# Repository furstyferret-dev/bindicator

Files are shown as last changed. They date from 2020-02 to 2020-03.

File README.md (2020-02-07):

# bindicator
## Overview
A bin collection notifier partly inspired by [this Twitter post](https://twitter.com/tarbard/status/1002464120447397888?lang=en) by Darren Tabard. Significant changes include collection schedule download from a Google Calendar, OLED display support, use of two NeoPixel Rings for greater brightness, and a capacitive touch sensor to cancel the reminder.

### Click on images to see videos
Watch the video (https://youtu.be/CMq2k3gbSQc)

## How it works
This is a project in two parts - simple Arduino code running on an ESP8266 handles the WiFi connection, drives the NeoPixel, and regularly downloads calendar events in JSON format from a Google Calendar. On first start it will launch a captive portal access point (SSID "Bindicator"), where you must supply a Google Scripts App ID for your calendar.  

Once connected any collections will cause the Bindicator to light up 24 hours before. Tapping the top of the "bin" will cancel the reminder. Multiple collections (three maximum) on the same day will show as the colour cycling. Colour is determined by the colour chosen for the event in Google Calendar. If the reminder is ignored, it will auto-cancel at 8.00am on the day of collection.

Calendar data is refreshed every 20 minutes.

Watch the video (https://youtu.be/yja5Ed7apo8)

## Make your own
### Parts list
1. [ESP8266 development board with OLED (any ESP8266 will work)](https://www.amazon.co.uk/gp/product/B076S8S6HL/ref=ox_sc_act_title_1?smid=A1QGN06QN25C35&psc=1) OR [Makerfire D1 Mini or clone](https://www.amazon.co.uk/Makerfire-NodeMcu-ESP8266-Internet-Development/dp/B07KYFZD17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)
2. [NeoPixel 7-LED ring (or generic equivalent) * 2](https://www.amazon.co.uk/gp/product/B07L82MSC9/ref=ox_sc_act_title_2?smid=A3TQ6TJY5HYALR&psc=1)
3. [Generic capacitive touch sensor](https://www.amazon.co.uk/ARCELI-2-5-5-5V-Capacitive-Self-Lock-Arduino/dp/B07BVN4CNH/)

### Arduino code
The Arduino code is plug-and-play. Further information on customising the program is available below.

> If you're using a plain ESP8266 board you should comment out the DISPLAY definition on line 18.

### Google script
Instead of trying to download and parse an entire calendar, the heavy lifting is handled by a Google Script. Go to [Google Scripts](https://script.google.com/home) and create a new project. Copy and paste the code from the GoogleScript.gs file, save it, and publish it.

**You need to save the API ID at this point**. This is the section of the URL from /macros/s through to /exec (see below in bold):
> https://script.google.com/macros/s/**AKfycbzcUsdfsdfsdltDtBHlbgde_9fXQvYMuddsvGhHFIGcSl3wr_5k**/exec

You'll need to supply this ID when you set up the Bindicator for the first time, otherwise it'll just show you my bin collection calendar.

### Soldering
Minimal soldering required. You'll need to solder wires to the NeoPixels and touch sensor. The NeoPixels support loop-in-and-out for data, saving a pin on the ESP8266. Dupont jumper wires can be used to connect to the board. I removed the plastic connector and replaced it with thin heat shrink tube to allow more flexibility when squashing everything into the base. 

NeoPixels and the button are happy on either 3.3 or 5V. I would not recommend running both from 3.3V as the on-board regulator will struggle, but the 5V side should be fine, as is a mixture of both.

Important: The D1 Mini only has one ground. Either loop through both NeoPixels and then on to the button, or solder a couple of header pins horizontally to the top of the USB port (common ground). 

### 3D print
I've modified a [fantastic model of a wheelie bin / trash can](https://www.thingiverse.com/thing:1935572) by DrLex. You'll need to download the wheels and axles from Thingiverse because I've not edited them. I've changed the bin model to include a mounting ring for the NeoPixel and a housing for the capacitive touch switch. I'd recommend printing with extra solid layers both on the sides and the top. I've used transparent PLA and white. White is best. Grey definitely doesn't work. :-)

If you use transparent PLA you may wish to print a diffuser which drops on top of the LED ring. This makes the light much easier to see in daylight, and prevents colour fringing effects from the layer lines.

I hot-glued the button and NeoPixel to the lid. 

[Here's the Thingiverse remix](https://www.thingiverse.com/thing:4147342)

Watch the video (https://youtu.be/6T-8IIQMk4Q)

## LED colours
* **Pulsing White**: Connecting to WiFi
* **Solid White**: Downloading calendar data
* **Magenta (at startup)**: WiFi portal running
* **Magenta**: Reminder cancelled
* **Red**: Unable to connect to WiFi

## Troubleshooting
**Can't connect to WiFi.**
The ESP8266 will only connect to 2.4GHz networks. If the captive portal isn't working properly, you can easily hard-code the SSID / password / Google Script ID into the Arduino program.

**I can connect but then see a single red flash**
Check your Google Script ID. This is a response to a 404, which Google returns if the script ID is wrong. See above.

**Corrupted names on the OLED display.**
I think this is a memory leak from the Linked List which handles events. The reality is that I'm not sure why it's happening. If you don't like it just reboot the Bindicator.

**Colours aren't distinctive.**
I'd recommend sticking with strong primary colours (green / blue / orange etc) instead of the paler equivalents. The brightness variable may help here, as would implementing the gamma correction function available from Adafruit. If you don't like them, they're easily corrected (8 bit RGB values).

**Generic "it's not working!"**
The ESP8266 is quite particular over pins used for GPIO, especially at boot. Check the various pin-outs on Google for recommendations. The numbers silk-screened onto the board do not correspond with the Arduino IDE assignment. 

You could also uncomment the DEBUG flag in the DebugMacros.h file which will provide more information through the serial monitor.

## Improvements
Reducing the reliance on hot-glue would be a start. I wasn't aware of NeoPixel linear boards when I built this, which could be used to create some very interesting effects if mounted on the inside back wall of the model.

## Thanks
* Darren Tabard [for the inspiration](https://twitter.com/tarbard/status/1002464120447397888?lang=en).
* DrLex for the [incredible 3D model](https://www.thingiverse.com/thing:1935572).
* Adafruit for their NeoPixel Library.
* Arkhipenko for the [TaskScheduler Library](https://github.com/arkhipenko/TaskScheduler) library.
* ElectronicsGuy for his [HTTPSRedirect library](https://github.com/electronicsguy/ESP8266/tree/master/HTTPSRedirect), without which this wouldn't be possible.
* Olikraus's [u8g2 display library and fonts](https://github.com/olikraus/u8g2).
* [ArduinoJSON](https://arduinojson.org/).

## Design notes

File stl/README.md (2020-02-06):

### 3D model remixed from original Thingiverse design:
https://www.thingiverse.com/thing:1935572

### Thingiverse link:
https://www.thingiverse.com/thing:4147342

### Changes made:
* Base added
* Cutout in bottom for wiring / header pins
* Neopixel holders
* Lid modified to hold capacitive touch sensor
* Cable routing

### Print settings:
Printed on a Flashforge Finder using white PLA, temperature 190C. 0.12mm layer thickness with four perimeter walls and supports under the wheel arches.

Infil is 3D at 10% on the body, and default hexagon on the base.

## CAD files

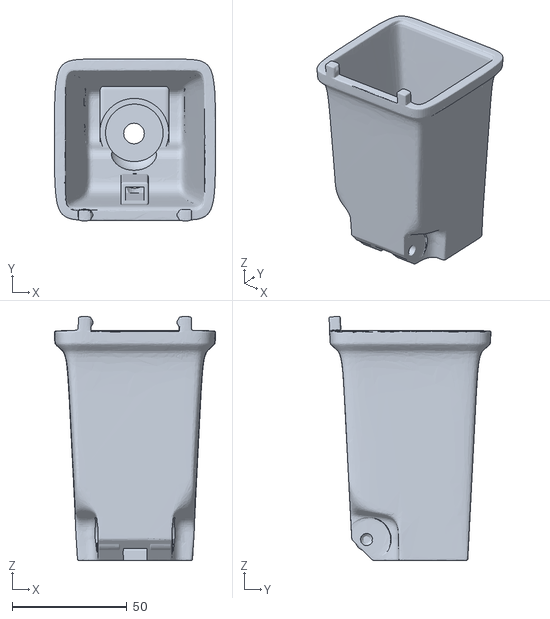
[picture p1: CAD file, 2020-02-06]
stl/Bin Body.stl
70.1 x 70.4 x 106.1

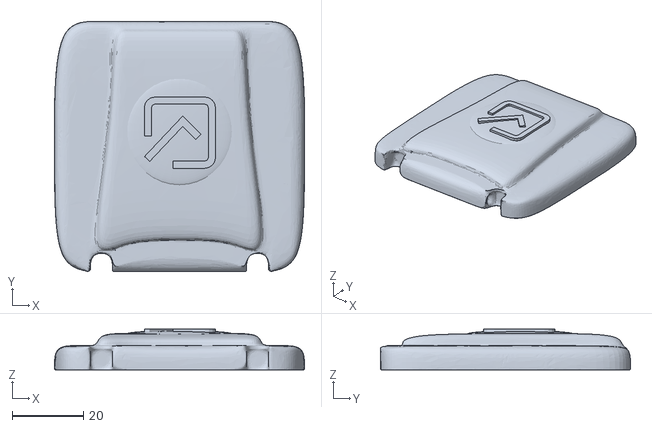
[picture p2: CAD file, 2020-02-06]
stl/Lid (no supports).stl
70.2 x 70.2 x 11.5

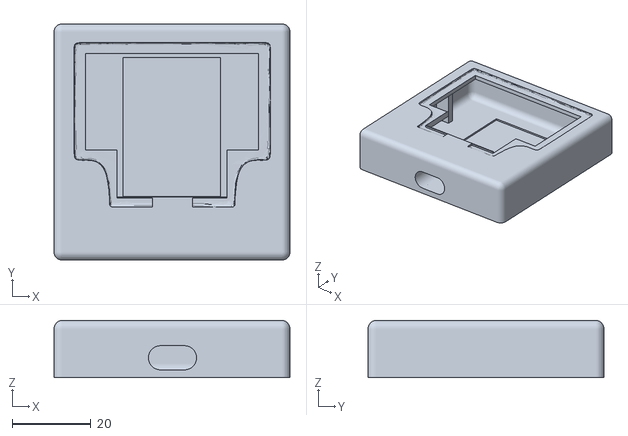
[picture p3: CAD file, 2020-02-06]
stl/Base.stl
60.0 x 60.0 x 14.5

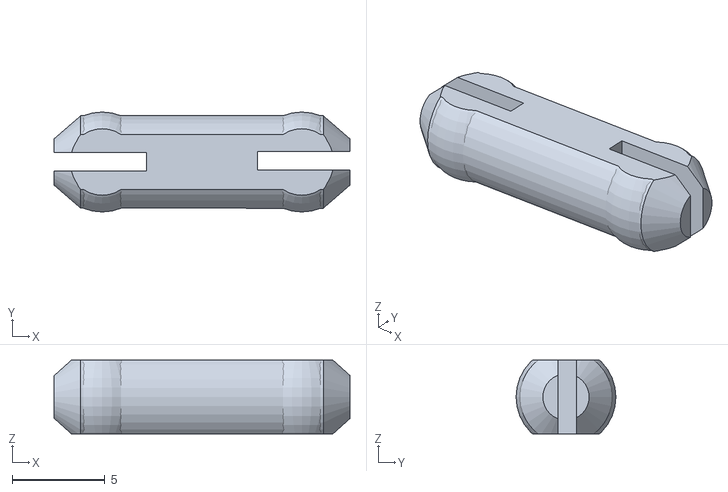
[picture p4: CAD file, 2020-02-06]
stl/TrashCan-axle.stl
16.0 x 5.40 x 4.00

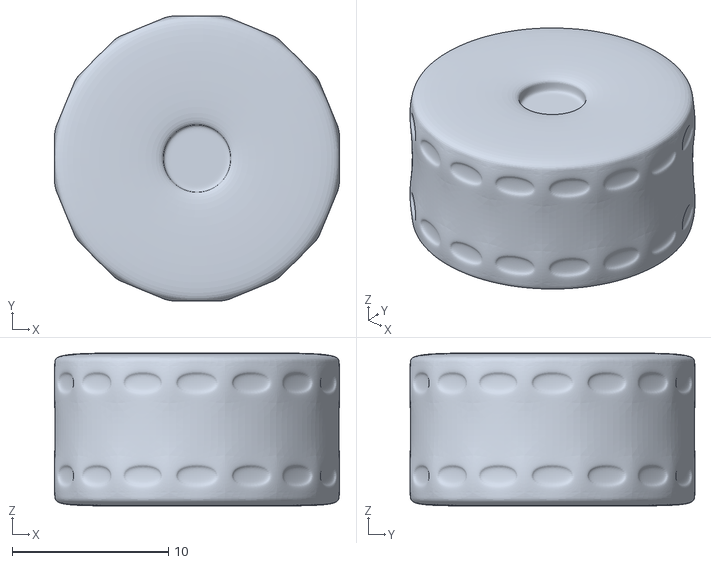
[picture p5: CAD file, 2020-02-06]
stl/TrashCan-wheel.stl
18.2 x 18.2 x 9.78

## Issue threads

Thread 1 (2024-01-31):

STL file missing

Craig-Ingram, 2024-01-31:
Hello, I get a 404 error when I click the link for the modified STL. Can you please reupload?
Cheers

Craig-Ingram, 2024-01-31:
Found the SLT on the repo. Thanks

Closed 2024-01-31.

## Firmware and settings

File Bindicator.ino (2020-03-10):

#include <FS.h>
#include <WiFiManager.h>
#include <TaskScheduler.h>
#include <TaskSchedulerDeclarations.h>
#include <TaskSchedulerSleepMethods.h>
#include <U8g2lib.h>
#include <ArduinoJson.h>
#include <ESP8266WiFi.h>
#include <Adafruit_NeoPixel.h>
#include <WS2812FX.h>
#include "HTTPSRedirect.h"
#include "LinkedList.h"
#include "DebugMacros.h"

#define SECOND            1000
#define MINUTE            SECOND * 60
#define HOUR              MINUTE * 60

//#define DISPLAY                             // Comment out if your ESP8266 doesn't have a display
#define POWER_LED         true                // Illuminate the built-in LED when power supplied       
#define VERSION           "v3.10b"            // Version information
#define PORTAL_SSID       "Bindicator"        // SSID for web portal
#define SCROLLING         true                // If false, use the button to change page
#define LED_PIN           15                  // NeoPixel data pin
#define TOUCH_PIN         13                  // Capacitive touch data pin
#define RESET_PIN         16                  // Display reset
#define CLOCK_PIN         5                   // Display clock
#define DATA_PIN          4                   // Display data
#define LED_COUNT         12                  // Number of pixels
#define BRIGHTNESS        255                 // NeoPixel brightness (0 - 255)
#define SPEED             1000                // Animation speed (lower is faster)
#define WIFI_TIMEOUT      5 * SECOND          // Delay in seconds before WiFi connection times out
#define WATCHDOG_TIMEOUT  60 * SECOND         // Delay in seconds before watchdog reboots device
#define CONFIG_DELAY      3 * SECOND          // Delay in seconds before enabling WiFi config at boot
#define LED_INTERVAL      2 * SECOND          // Interval in second between event colour changing
#define REFRESH_INTERVAL  10 * MINUTE         // Data refresh interval
#define NIGHT_BRT         150                  // Night light brightness (0 - 255)
#define HALOGEN_HUE       5643                // Night light colour temperature
#define HALOGEN_SAT       80                  // Night light saturation

int modes[3] = { FX_MODE_STATIC, FX_MODE_RAINBOW, FX_MODE_CUSTOM };
int modeIndex = FX_MODE_STATIC; 

struct Event {                          // All events contain a title and associated colour
  const char* title;                    
  uint32_t color;
};

LinkedList<struct Event> eventList;     // Downloaded calendar events go here

Adafruit_NeoPixel pixel = Adafruit_NeoPixel(LED_COUNT, LED_PIN, NEO_GRB + NEO_KHZ800);
WS2812FX ws2812fx = WS2812FX(LED_COUNT, LED_PIN, NEO_GRB + NEO_KHZ800);

#ifdef DISPLAY
U8G2_SSD1306_128X32_UNIVISION_F_HW_I2C u8g2(U8G2_R0, RESET_PIN, CLOCK_PIN, DATA_PIN);
int page;                               // Incremented to change page when button touched and no collection scheduled
#endif

const char* host = "script.google.com";                                           // Base URL for Google Apps
const int httpsPort = 443;                                                        // Default HTTPS port
char *GScriptId = "xxxxxxxxxxxxxxxxxxxxxxxxxxxxxxxxxxxxxxxxxxxxxxxxxxxxxxxx";     // Default script ID

String eventsUrl = String("/macros/s/") + GScriptId + "/exec";                    // URL to retrieve calendar entries [GET]
String clearUrl = String("/macros/s/") + GScriptId + "/exec?clear";               // URL to clear active events [POST]

HTTPSRedirect* client = nullptr;                                                  // This client handles the redirection used by Google
WiFiManagerParameter custom_gScriptId(                                            // Custom parameter if Google Script ID is changed
  "gscriptid", "Google App ID", GScriptId, 56);

void neopixelCallback();                                                          // Task scheduler function for updating the NeoPixel and display
void getEventsCallback();                                                         // Task scheduler function for refreshing event data
void cancelEventsCallback();                                                      // Task scheduler function for cancelling upcoming events
void wiFiWatchdogCallback();                                                      // Task scheduler function for monitoring WiFi connection

Scheduler ts;                                                                     // Responsible for all repeating functions
Task tShowEventColor(LED_INTERVAL, TASK_FOREVER, &neopixelCallback);              // Task to convert events to NeoPixel colours
Task tUpdateData(REFRESH_INTERVAL, TASK_FOREVER, &getEventsCallback);             // Task to update the list of calendar events
Task tCancelEvents(SECOND / 2, TASK_FOREVER, &cancelEventsCallback);              // Task to poll the capacitive button
Task tWiFiWatchdog(SECOND, TASK_FOREVER, &wiFiWatchdogCallback);                  // Task to monitor WiFi and reconnect if necessary
  

void setup() {
  pinMode(TOUCH_PIN, INPUT);                 // Set the pin connected to the touch sensor to input
  if (POWER_LED) {                           // Turn on the built-in LED if enabled above
  pinMode(LED_BUILTIN, OUTPUT);
  digitalWrite(LED_BUILTIN, LOW);
  }

  delay(1000);

#ifdef DEBUG
  Serial.begin(115200);                     
  Serial.flush();
  DPRINTLN("Serial Transmission Begin");
#endif

  initialiseNeoPixel();                     // NeoPixel won't work without initialisation

#ifdef DISPLAY
  u8g2.begin();
  u8g2.setFontMode(0);                      // Enable transparent mode, which is faster
  u8g2.clearBuffer();                       // Clear the internal memory
  u8g2.setFont(u8g2_font_helvR14_tr);       // Choose a suitable font
  u8g2.drawStr(20, 14, "Bindicator");
  u8g2.setFont(u8g2_font_helvR14_tr);
  u8g2.drawStr(38, 32, VERSION);
  u8g2.sendBuffer();                        // Transfer internal memory to the display
#endif

  DPRINTLN("Mounting FS...");
  if (SPIFFS.begin()) {                                                 // If file system is valid get configuration data
    DPRINTLN("Mounted file system");
    if (SPIFFS.exists("/config.json")) {                                // File exists, reading and loading

      DPRINTLN("Reading config file");
      File configFile = SPIFFS.open("/config.json", "r");
      if (configFile) {
        DPRINTLN("Opened config file");
        size_t size = configFile.size();
        std::unique_ptr<char[]> buf(new char[size]);                   // Allocate a buffer to store contents of the file
        configFile.readBytes(buf.get(), size);

        DynamicJsonDocument doc(size);                                 // Deserialise JSON data
        deserializeJson(doc, buf.get());
        DeserializationError err = deserializeJson(doc, buf.get());

        if (!err) {
          JsonObject root = doc[0];                                    // If the config file is valid, copy the script ID
          strcpy(GScriptId, root["GScriptId"]);
        }
        configFile.close();
      }
    }
  } else {
    DPRINTLN("Failed to mount FS");
  }

  unsigned long startTime = millis();
  ws2812fx.setMode(FX_MODE_COLOR_WIPE);
  ws2812fx.setColor(MAGENTA);
  while (digitalRead(TOUCH_PIN) == HIGH)      // If so wait until approx 5 seconds have passed
  {                                           // then start WiFi Configuration
    DPRINTLN("Touch pin high");
    if (millis() > startTime + (CONFIG_DELAY))
    {
      configWiFi();   
      return;
    }    
    ws2812fx.service();
  }

  DPRINTLN();                               // Debugging info
  DPRINT("Connecting to WiFi: ");

  WiFi.softAPdisconnect(true);              // Stop broadcasting SSID from setup mode (ESP8266 bug)
  WiFi.begin();  
  
  ws2812fx.setColor(WHITE);
  ws2812fx.setMode(FX_MODE_FADE);           
  
  startTime = millis();  
  while (WiFi.status() != WL_CONNECTED) {
    ws2812fx.service();
    DPRINT(".");
    if (millis() > startTime + (WIFI_TIMEOUT)) 
    {                                                   // It's trivial to change this to start WiFi configuration
      ws2812fx.fill(ws2812fx.ColorHSV(RED));            // at this point.
      ws2812fx.show();
      DPRINTLN();
      DPRINTLN("WiFi Timeout");
      while (true) 
      { 
        if (millis() < WATCHDOG_TIMEOUT)        // Wait 60 seconds then reboot in attempt to recover WiFi
          ESP.wdtFeed(); 
        }
#ifdef DISPLAY
      u8g2.clearBuffer();                       // Clear the internal memory
      u8g2.setFont(u8g2_font_helvR14_tr);       // Choose a suitable font
      u8g2.drawStr(0, 14, "Error joining");     // Write title to the buffer
      u8g2.drawStr(0, 32, "WiFi network");
      u8g2.sendBuffer();                        // Transfer internal memory to the display
#endif
      return;
    }
  }
  DPRINTLN("");                             // Debugging info
  DPRINTLN("WiFi connected");
  DPRINTLN("IP address: ");
  DPRINTLN(WiFi.localIP());

  ts.init();                                // Task Scheduler initialisation
  ts.addTask(tShowEventColor);              // Add tasks
  ts.addTask(tUpdateData);                  // ...
  ts.addTask(tCancelEvents);                // ...
  ts.addTask(tWiFiWatchdog);                // ....
  tUpdateData.enable();                     // Connected and ready to start getting event data
  tCancelEvents.enable();                   // Allow use of capacitive button
  tWiFiWatchdog.enable();
}

void loop() {
  ts.execute();                               // Task scheduler handles all repeating functions
  ws2812fx.service();                         // WS2812 animation 
}

void neopixelCallback() {
  DPRINTLN(ESP.getFreeHeap());  
  if (eventList.getLength() > 0)              // If items to show...
  {
    switch (eventList.getLength())
    {
      case 1:
      if (ws2812fx.getMode() != FX_MODE_BREATH)
        ws2812fx.setMode(FX_MODE_BREATH);
      break;

      case 2:
      if (ws2812fx.getMode() != FX_MODE_STATIC)
        ws2812fx.setMode(FX_MODE_STATIC);
      break;

      default:
      if (ws2812fx.getMode() != FX_MODE_STATIC)
        ws2812fx.setMode(FX_MODE_STATIC);
    }
    
    struct Event e = eventList.getCurrent();
    ws2812fx.setColor(e.color);
    eventList.loop();                         // Move to the next item
#ifdef DISPLAY
    u8g2.clearBuffer();                       // Clear the internal memory
    u8g2.setFont(u8g2_font_helvR14_tr);       // Choose a suitable font
    u8g2.drawStr(0, 14, "Next collection");   // Write title to the buffer
    u8g2.drawStr(0, 32, e.title);
    DPRINTLN(e.title);
    u8g2.sendBuffer();                        // Transfer internal memory to the display
#endif
  } else
  {
    tidyUp();

#ifdef DISPLAY
    switch (page % 3)
    {
      case 0:                                     // Page 1
        u8g2.clearBuffer();                       // Clear the internal memory
        u8g2.setFont(u8g2_font_helvR14_tr);       // Choose a suitable font
        u8g2.drawStr(0, 14, "Free heap");         // Write the free heap to the buffer
        char buf[32];
        itoa(ESP.getFreeHeap(), buf, 10);
        u8g2.drawStr(0, 32, buf);
        u8g2.drawStr(53, 32, "kb");
        u8g2.sendBuffer();                        // Transfer internal memory to the display
        break;

      case 1:                                     // Page 2
        u8g2.clearBuffer();                       // Clear the internal memory
        u8g2.setFont(u8g2_font_helvR14_tr);       // Choose a suitable font
        u8g2.drawStr(0, 14, "IP address");        // Write the title to the buffer
        u8g2.drawStr(0, 32, 
        WiFi.localIP().toString().c_str());       // Write the IP address to the buffer
        u8g2.sendBuffer();                        // Transfer internal memory to the display
        break;

      case 2:                                     // Page 3
        long t = 
        ts.timeUntilNextIteration(tUpdateData);   // Time until task runs again in millis
        u8g2.clearBuffer();                       // Clear the internal memory
        u8g2.setFont(u8g2_font_helvR14_tr);       // Choose a suitable font
        if (t == 0) {
          u8g2.drawStr(0, 14, "Next check");
          u8g2.drawStr(0, 32, "in progress.");
        }
        if (t == -1) {
          u8g2.drawStr(0, 14, "Calendar sync");
          u8g2.drawStr(0, 32, "is disabled.");
        }
        else {
          const char* text = showTimeFormatted(t);
          int mins = t / 60000;
          DPRINTLN(text);
          u8g2.drawStr(0, 14, "Next update");
          u8g2.drawStr(22, 32, "mins");
          u8g2.setCursor(0, 32);       
          u8g2.print(mins);
        }
        u8g2.sendBuffer();
    }
  }
#endif
}

void cancelEventsCallback() {
  if (digitalRead(TOUCH_PIN) == HIGH && eventList.getLength() > 0)   // Only run if the button is held down
  {                                                                  // and there are events to cancel
#ifdef DISPLAY
    u8g2.clearBuffer();                       // Clear the internal memory
    u8g2.setFont(u8g2_font_helvR14_tr);       // Choose a suitable font
    u8g2.drawStr(0, 14, "Cancelling");        // Write title to the buffer
    u8g2.drawStr(0, 32, "reminder...");
    u8g2.sendBuffer();                        // Transfer internal memory to the display
#endif
    ws2812fx.setColor(MAGENTA);
    ws2812fx.setMode(FX_MODE_STATIC);
    ws2812fx.service();

    // Use HTTPSRedirect class to create a new TLS connection
    client = new HTTPSRedirect(httpsPort);
    client->setInsecure();
    client->setPrintResponseBody(true);
    client->setContentTypeHeader("application/json");

    DPRINT("Connecting to ");
    DPRINTLN(host);

    // Try to connect for a maximum of 5 times
    bool flag = false;
    for (int i = 0; i < 5; i++) {
      int retval = client->connect(host, httpsPort);
      if (retval == 1) {
        flag = true;
        break;
      }
      else
        DPRINTLN("Connection failed. Retrying...");
    }

    if (!flag) {
      DPRINT("Could not connect to server: ");
      DPRINTLN(host);
      DPRINTLN("Exiting...");
      return;
    }

    client->POST(clearUrl, host, "", false);        // Send empty POST string

    delete client;                                  // Delete HTTPSRedirect object
    client = nullptr;                               // COMMENT THIS LINE IF PROGRAM CRASHES

    tidyUp();

    eventList.Clear();                              // Empty the event list
    getEventsCallback();                            // Update events list to make sure they were
    return;                                         // successfully cancelled
  }

#ifdef DISPLAY
  if (!SCROLLING && digitalRead(TOUCH_PIN) == HIGH)
      page++;                                       // Increment page number (modulo)
      else
        page++;
#endif

  unsigned long startTime = millis();
  if (digitalRead(TOUCH_PIN) == HIGH && eventList.getLength() == 0) 
  {
      modeIndex++;                                  // Cycle nightlight modes
      modeIndex = modeIndex % 3;
      ws2812fx.setMode(modes[modeIndex]);
      tidyUp();
      DPRINT("Mode: ");
      DPRINTLN(modeIndex);
  }
  }

void getEventsCallback()
{
  DPRINTLN(ESP.getFreeHeap());

  client = new HTTPSRedirect(httpsPort);            
  client->setInsecure();
  client->setPrintResponseBody(true);
  client->setContentTypeHeader("application/json"); // Expecting a JSON response

  DPRINTLN("Connecting to ");
  DPRINTLN(host);

  // Try to connect for a maximum of 5 times
  bool flag = false;
  for (int i = 0; i < 5; i++) {
    int retval = client->connect(host, httpsPort);
    if (retval == 1) {
      flag = true;
      break;
    }
    else
      DPRINTLN("Connection failed. Retrying...");
  }

  if (!flag) {
    DPRINTLN("Could not connect to server: ");
    DPRINTLN(host);
    DPRINTLN("Exiting...");
    return;
  }

  if (client->GET(eventsUrl, host))
    if (client->getStatusCode() == 200)             // Valid response
    {
      DPRINTLN(ESP.getFreeHeap());
      DPRINTLN("Response Body: ");
      parseJson(client->getResponseBody());
      DPRINT(client->getResponseBody());
    }

    if (client->getStatusCode() == 404)             // 404 - script ID probably wrong
    {
      DPRINTLN("404 - confirm Gscript ID");
      pixel.fill(pixel.ColorHSV(RED));         
      pixel.show();
#ifdef DISPLAY
      u8g2.clearBuffer();                         // Clear the internal memory
      u8g2.setFont(u8g2_font_helvR14_tr);         // Choose a suitable font
      u8g2.drawStr(0, 14, "Update failed");       // Write title to the buffer
      u8g2.drawStr(0, 32, "Check API ID");
      u8g2.sendBuffer();                          // Transfer internal memory to the display
#endif
    }

  // Delete HTTPSRedirect object
  delete client;
  client = nullptr;
  tShowEventColor.enableDelayed(SECOND * 3);      // Brief delay so errors visible to user
}

void parseJson(String json) {

  const size_t capacity = JSON_ARRAY_SIZE(3) + 3 * JSON_OBJECT_SIZE(2) + 1024; // Additional bytes for string duplication
  DynamicJsonDocument doc(capacity);

  deserializeJson(doc, json);
  DeserializationError err = deserializeJson(doc, json);

  if (err) {
    DPRINTLN(F("deserializeJson() failed with code "));
    DPRINTLN(err.c_str());
    return;
  }

  JsonObject root;                                 // This object contains an array of JSON events
  eventList.Clear();                               
  for (int i = 0; i < doc.size(); i++)
  {
    DPRINTLN(ESP.getFreeHeap());
    struct Event e;                                // For each event, create a struct and populate data
    root = doc[i];
    e.title = root["title"];
    e.color = eventColor2RealColor(atoi(root["color"]));
    eventList.Append(e);                           // Add event to list
  }
}

/******************** WIFI FUNCTIONS ************************/

void configWiFi() {
#ifdef DISPLAY
    u8g2.clearBuffer();                       // Clear the internal memory
    u8g2.setFont(u8g2_font_helvR14_tr);       // Choose a suitable font
    u8g2.drawStr(24, 23, "WiFi Setup");       // Write title to the buffer
    u8g2.sendBuffer();                        // Transfer internal memory to the display
#endif

  WiFiManager wifiManager;                                 // Handles WiFi configuration via captive portal
  wifiManager.setSaveConfigCallback(saveConfigCallback);   // This function called if data updated
  wifiManager.addParameter(&custom_gScriptId);             // Add a custom parameter for the Google Apps ID
  wifiManager.startConfigPortal(PORTAL_SSID);              // Start an open access point
  DPRINTLN("Wifi Configuration started");
}

void saveConfigCallback()
{
  strcpy(GScriptId, custom_gScriptId.getValue());          // Read updated parameters

  DPRINTLN("Saving config");
  StaticJsonDocument<128> doc;                             
  doc["GScriptId"] = GScriptId;                            

  File configFile = SPIFFS.open("/config.json", "w");      
  if (!configFile) {
    DPRINTLN("Failed to open config file for writing");
  }

  if (serializeJson(doc, configFile) == 0) {
    DPRINTLN(F("Failed to write to file"));
  }
  configFile.close();

  DPRINTLN("Restarting in 5 seconds");
#ifdef DISPLAY
    u8g2.clearBuffer();                       // Clear the internal memory
    u8g2.setFont(u8g2_font_helvR14_tr);       // Choose a suitable font
    u8g2.drawStr(0, 14, "Restarting");        // Write title to the buffer
    u8g2.drawStr(0, 32, "in 5 seconds");
    u8g2.sendBuffer();                        // Transfer internal memory to the display
#endif
  delay(5000);
  ESP.restart();
}

void wiFiWatchdogCallback() {
  unsigned long startTime = millis();
  
  while (WiFi.status() != WL_CONNECTED)
  {
    if (millis() > startTime + WATCHDOG_TIMEOUT)
      ESP.restart();
    ws2812fx.setColor(RED);
    ws2812fx.setBrightness(BRIGHTNESS);
    ws2812fx.setMode(FX_MODE_BLINK);
    ws2812fx.service();
    WiFi.begin();
  }
}

/********************** NEOPIXEL HELPER FUNCTIONS ***************************/

// Needed to use the WS2812 LEDs
// MUST BE CALLED
void initialiseNeoPixel()
{
  ws2812fx.init();
  ws2812fx.setBrightness(BRIGHTNESS);
  ws2812fx.setSpeed(SPEED);
  ws2812fx.setColor(0x007BFF);
  ws2812fx.setMode(FX_MODE_STATIC);
  ws2812fx.setCustomMode(customEffect);
  ws2812fx.start();
}

uint32_t eventColor2RealColor(int eventColor)
{
  switch (eventColor)
  {
    case 0:
      return PINK;
      break;

    case 1:
      return CYAN;
      break;

    case 2:
      return ws2812fx.Color(75, 255, 120);
      break;

    case 3:
      return ws2812fx.Color(190, 175, 255);
      break;

    case 4:
      return ws2812fx.Color(255, 50, 50);
      break;

    case 5:
      return YELLOW;
      break;

    case 6:
      return ORANGE;
      break;

    case 7:
      return CYAN;
      break;

    case 8:
      return WHITE;
      break;

    case 9:
      return BLUE;
      break;

    case 10:
      return GREEN;
      break;

    case 11:
      return RED;
      break;

    default:
      return WHITE;
  }
}

void tidyUp() {
  if (ws2812fx.getMode() != modes[modeIndex])
      ws2812fx.setMode(modes[modeIndex]);
//    if (ws2812fx.getMode() == FX_MODE_STATIC)
//      ws2812fx.setColor(ws2812fx.ColorHSV(0, 0, NIGHT_BRT));
    if (ws2812fx.getMode() == FX_MODE_STATIC)
      ws2812fx.setColor(ws2812fx.gamma32(ws2812fx.ColorHSV(HALOGEN_HUE, HALOGEN_SAT, NIGHT_BRT)));
    if (ws2812fx.getMode() == FX_MODE_FIRE_FLICKER_SOFT)
      ws2812fx.setColor(0xE25822);
    if (ws2812fx.getMode() == FX_MODE_COMET || ws2812fx.getMode() == FX_MODE_LARSON_SCANNER)
      ws2812fx.setColor(0x0000FF);    
}

uint16_t customEffect(void) { 
  WS2812FX::Segment* seg = ws2812fx.getSegment(); 
  ws2812fx.clear();
  return seg->speed; // Return the delay until the next animation step (in ms)
}
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

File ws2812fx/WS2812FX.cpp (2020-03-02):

/*
  WS2812FX.cpp - Library for WS2812 LED effects.

  Harm Aldick - 2016
  www.aldick.org


  FEATURES
    * A lot of blinken modes and counting
    * WS2812FX can be used as drop-in replacement for Adafruit NeoPixel Library

  NOTES
    * Uses the Adafruit NeoPixel library. Get it here:
      https://github.com/adafruit/Adafruit_NeoPixel



  LICENSE

  The MIT License (MIT)

  Copyright (c) 2016  Harm Aldick

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

  CHANGELOG

  2016-05-28   Initial beta release
  2016-06-03   Code cleanup, minor improvements, new modes
  2016-06-04   2 new fx, fixed setColor (now also resets _mode_color)
  2017-02-02   added external trigger functionality (e.g. for sound-to-light)
  2017-02-02   removed "blackout" on mode, speed or color-change
  2017-09-26   implemented segment and reverse features
  2017-11-16   changed speed calc, reduced memory footprint
  2018-02-24   added hooks for user created custom effects
*/

#include "WS2812FX.h"

void WS2812FX::init() {
  resetSegmentRuntimes();
  Adafruit_NeoPixel::begin();
}

// void WS2812FX::timer() {
//     for (int j=0; j < 1000; j++) {
//       uint16_t delay = (this->*_mode[SEGMENT.mode])();
//     }
// }

void WS2812FX::service() {
  if(_running || _triggered) {
    unsigned long now = millis(); // Be aware, millis() rolls over every 49 days
    bool doShow = false;
    for(uint8_t i=0; i < _num_segments; i++) {
      _segment_index = i;
      CLR_FRAME;
      if(now > SEGMENT_RUNTIME.next_time || _triggered) {
        SET_FRAME;
        doShow = true;
        uint16_t delay = (this->*_mode[SEGMENT.mode])();
        SEGMENT_RUNTIME.next_time = now + max(delay, SPEED_MIN);
        SEGMENT_RUNTIME.counter_mode_call++;
      }
    }
    if(doShow) {
      delay(1); // for ESP32 (see https://forums.adafruit.com/viewtopic.php?f=47&t=117327)
      show();
    }
    _triggered = false;
  }
}

// overload setPixelColor() functions so we can use gamma correction
// (see https://learn.adafruit.com/led-tricks-gamma-correction/the-issue)
void WS2812FX::setPixelColor(uint16_t n, uint32_t c) {
  if(IS_GAMMA) {
    uint8_t w = (c >> 24) & 0xFF;
    uint8_t r = (c >> 16) & 0xFF;
    uint8_t g = (c >>  8) & 0xFF;
    uint8_t b =  c        & 0xFF;
    Adafruit_NeoPixel::setPixelColor(n, gamma8(r), gamma8(g), gamma8(b), gamma8(w));
  } else {
    Adafruit_NeoPixel::setPixelColor(n, c);
  }
}

void WS2812FX::setPixelColor(uint16_t n, uint8_t r, uint8_t g, uint8_t b) {
  if(IS_GAMMA) {
    Adafruit_NeoPixel::setPixelColor(n, gamma8(r), gamma8(g), gamma8(b));
  } else {
    Adafruit_NeoPixel::setPixelColor(n, r, g, b);
  }
}

void WS2812FX::setPixelColor(uint16_t n, uint8_t r, uint8_t g, uint8_t b, uint8_t w) {
  if(IS_GAMMA) {
    Adafruit_NeoPixel::setPixelColor(n, gamma8(r), gamma8(g), gamma8(b), gamma8(w));
  } else {
    Adafruit_NeoPixel::setPixelColor(n, r, g, b, w);
  }
}

void WS2812FX::copyPixels(uint16_t dest, uint16_t src, uint16_t count) {
  uint8_t *pixels = getPixels();
  uint8_t bytesPerPixel = getNumBytesPerPixel(); // 3=RGB, 4=RGBW

  memmove(pixels + (dest * bytesPerPixel), pixels + (src * bytesPerPixel), count * bytesPerPixel);
}

// overload show() functions so we can use custom show()
void WS2812FX::show(void) {
  if(customShow == NULL) {
    Adafruit_NeoPixel::show();
  } else {
    customShow();
  }
}

void WS2812FX::start() {
  resetSegmentRuntimes();
  _running = true;
}

void WS2812FX::stop() {
  _running = false;
  strip_off();
}

void WS2812FX::pause() {
  _running = false;
}

void WS2812FX::resume() {
  _running = true;
}

void WS2812FX::trigger() {
  _triggered = true;
}

void WS2812FX::setMode(uint8_t m) {
  setMode(0, m);
}

void WS2812FX::setMode(uint8_t seg, uint8_t m) {
  resetSegmentRuntime(seg);
  _segments[seg].mode = constrain(m, 0, MODE_COUNT - 1);
}

void WS2812FX::setOptions(uint8_t seg, uint8_t o) {
  _segments[seg].options = o;
}

void WS2812FX::setSpeed(uint16_t s) {
  setSpeed(0, s);
}

void WS2812FX::setSpeed(uint8_t seg, uint16_t s) {
//  resetSegmentRuntime(seg);
  _segments[seg].speed = constrain(s, SPEED_MIN, SPEED_MAX);
}

void WS2812FX::increaseSpeed(uint8_t s) {
  uint16_t newSpeed = constrain(SEGMENT.speed + s, SPEED_MIN, SPEED_MAX);
  setSpeed(newSpeed);
}

void WS2812FX::decreaseSpeed(uint8_t s) {
  uint16_t newSpeed = constrain(SEGMENT.speed - s, SPEED_MIN, SPEED_MAX);
  setSpeed(newSpeed);
}

void WS2812FX::setColor(uint8_t r, uint8_t g, uint8_t b) {
  setColor(((uint32_t)r << 16) | ((uint32_t)g << 8) | b);
}

void WS2812FX::setColor(uint8_t r, uint8_t g, uint8_t b, uint8_t w) {
  setColor((((uint32_t)w << 24)| ((uint32_t)r << 16) | ((uint32_t)g << 8)| ((uint32_t)b)));
}

void WS2812FX::setColor(uint32_t c) {
  setColor(0, c);
}

void WS2812FX::setColor(uint8_t seg, uint32_t c) {
//  resetSegmentRuntime(seg);
  _segments[seg].colors[0] = c;
}

void WS2812FX::setColors(uint8_t seg, uint32_t* c) {
//  resetSegmentRuntime(seg);
  for(uint8_t i=0; i<NUM_COLORS; i++) {
    _segments[seg].colors[i] = c[i];
  }
}

void WS2812FX::setBrightness(uint8_t b) {
  b = constrain(b, BRIGHTNESS_MIN, BRIGHTNESS_MAX);
  Adafruit_NeoPixel::setBrightness(b);
  show();
}

void WS2812FX::increaseBrightness(uint8_t s) {
  s = constrain(getBrightness() + s, BRIGHTNESS_MIN, BRIGHTNESS_MAX);
  setBrightness(s);
}

void WS2812FX::decreaseBrightness(uint8_t s) {
  s = constrain(getBrightness() - s, BRIGHTNESS_MIN, BRIGHTNESS_MAX);
  setBrightness(s);
}

void WS2812FX::setLength(uint16_t b) {
  resetSegmentRuntimes();
  if (b < 1) b = 1;

  // Decrease numLEDs to maximum available memory
  do {
      Adafruit_NeoPixel::updateLength(b);
      b--;
  } while(!Adafruit_NeoPixel::numLEDs && b > 1);

  _segments[0].start = 0;
  _segments[0].stop = Adafruit_NeoPixel::numLEDs - 1;
}

void WS2812FX::increaseLength(uint16_t s) {
  s = _segments[0].stop - _segments[0].start + 1 + s;
  setLength(s);
}

void WS2812FX::decreaseLength(uint16_t s) {
  if (s > _segments[0].stop - _segments[0].start + 1) s = 1;
  s = _segments[0].stop - _segments[0].start + 1 - s;

  for(uint16_t i=_segments[0].start + s; i <= (_segments[0].stop - _segments[0].start + 1); i++) {
    setPixelColor(i, 0);
  }
  show();

  setLength(s);
}

boolean WS2812FX::isRunning() {
  return _running;
}

boolean WS2812FX::isTriggered() {
  return _triggered;
}

boolean WS2812FX::isFrame() {
  return isFrame(0);
}

boolean WS2812FX::isFrame(uint8_t segIndex) {
  return (_segment_runtimes[segIndex].aux_param2 & FRAME);
}

boolean WS2812FX::isCycle() {
  return isCycle(0);
}

boolean WS2812FX::isCycle(uint8_t segIndex) {
  return (_segment_runtimes[segIndex].aux_param2 & CYCLE);
}

uint8_t WS2812FX::getMode(void) {
  return getMode(0);
}

uint8_t WS2812FX::getMode(uint8_t seg) {
  return _segments[seg].mode;
}

uint16_t WS2812FX::getSpeed(void) {
  return getSpeed(0);
}

uint16_t WS2812FX::getSpeed(uint8_t seg) {
  return _segments[seg].speed;
}


uint8_t WS2812FX::getOptions(uint8_t seg) {
  return _segments[seg].options;
}
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

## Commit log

2020-01-22 Fixed bug with cut-off time
2020-01-23 Fix for corrupted display labels
    [Bindicator.ino]
2020-02-06 v2.06b
    Pin assignments, night light mode (tap lid to turn on and off), minor fixes
    [Bindicator.ino]
